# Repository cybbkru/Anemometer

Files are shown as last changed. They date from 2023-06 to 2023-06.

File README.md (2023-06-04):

# Anemometer 
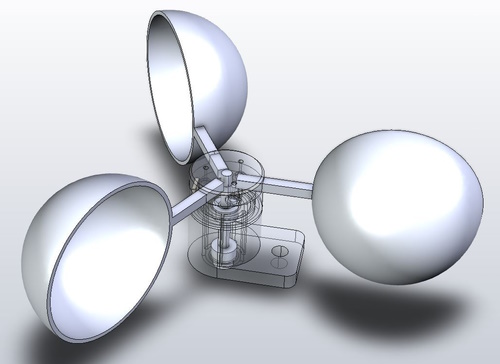
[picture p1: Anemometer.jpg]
"Main picture"


In my home ventilation unit this Anemometer helps to clear filters in time ( before air flow becomes too low). 

Hall-sensor and magnet are used to generate impulses according to rotation rate of Anemometer.

The "Sonoff basic" esp8266 wifi-relay flashed with Tasmota firmware used to count sesnsor impulses. (In my vent. unit it also enables/disables fan.)
You can use ANY ESP8266 based device (cheapest ESP-01 for example) having 1 free pin.

To count impulses attach Counter1 to RX pin of module (GPIO2 and GPIO14 are also available in some untits, you can try another available pin):
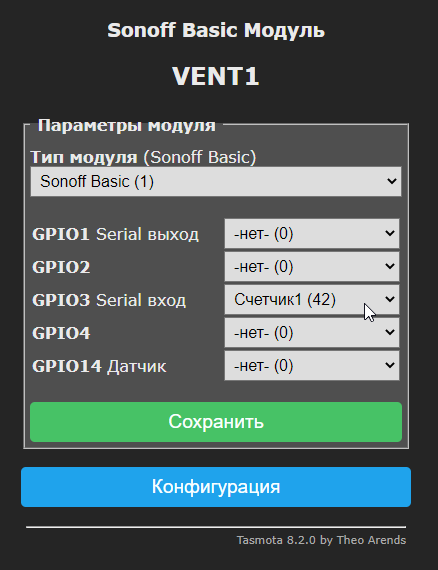
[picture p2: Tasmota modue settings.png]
"Settings"


Example for RX pin:
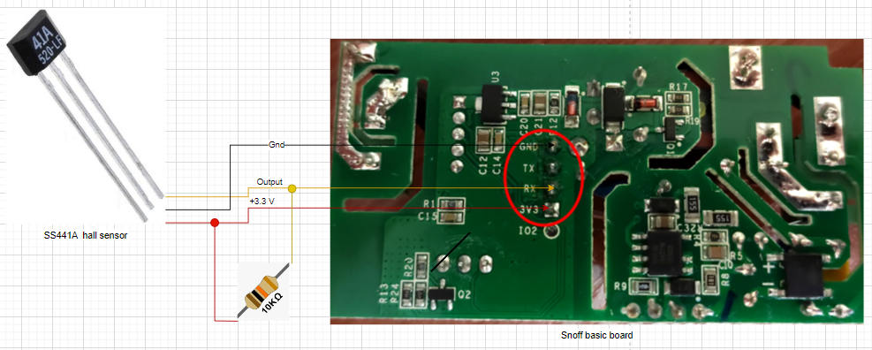
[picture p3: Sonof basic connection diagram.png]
"Wiring"


To publish counted impulses every 10 seconds to  MQTT topic "wind/vent1" use commands in Tasmota console:
```
Teleperiod 10
rule1 on tele-counter#c1>-1 do publish wind/vent1 %value% endon on tele-counter#c1>0 do counter1 0 endon
rule1 1
```

# Restrictions
Indoor use only.

# TODO
1. Draw printable bottom cover with cable gland.
2. Redraw design for outdoor use (enlarge clearances and parts overlays to prevent raindrops infiltration).

# TIPS
* Using eDrawings free STEP viewer to explore 3D model of assembled device (anemometer assembly.STEP) is more convenient than embedded STL-viewer of GitHUB.
* Test the magnet and SS441A BEFORE gluing magnet to printed part - this sensor is magnet direction sensitive! 
* SS441A is documented to work 3.8v and higher, using at 3.3 v is not good, but in my case 2 sensors work fine.
* STL files are ready to print.
* SolidWorks 2021 required to edit models.

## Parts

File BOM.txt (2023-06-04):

# BOM
Bearing D1=2mm D2=5mm h=2.5mm;        2 pcs;  to buy;
Steel pin D=2mm L=23mm (drill d=2mm); 1 pcs;  to buy;	
Hall sensor SS441A;                   1 pcs;  to buy;
Screw M1.2 L=3.5mm;                   3 pcs;  to buy;
Resistor 10k;                         1 pcs;  to buy;
Magnet 3.5 x 3.5 x 0.7 mm;            1 pcs;  to buy or to magnetize iron piece;

Cup;                                  3 pcs;  to print;
Base;                                 1 pcs;  to print;
Rayholder;                            1 pcs;  to print;
Rotor;                                1 pcs;  to print;
Lock;                                 1 pcs;  to print;

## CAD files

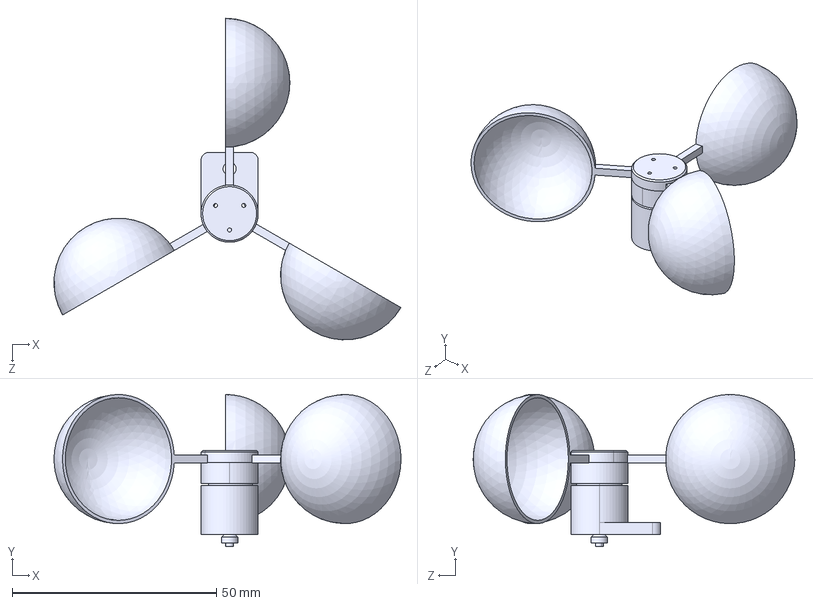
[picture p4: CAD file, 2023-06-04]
anemometer assembly.STEP
84.9 x 37.2 x 78.7 mm
cup x 3
rotor
axis
magnet
bearing x 2
rayholder
base
lock
ss441a

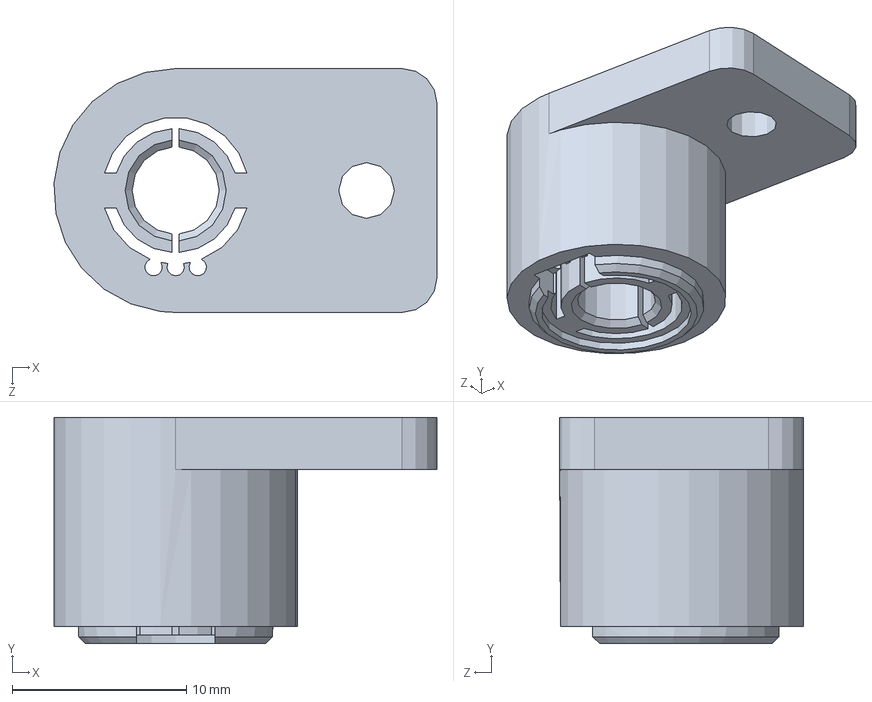
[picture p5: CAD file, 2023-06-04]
editable parts/base.SLDPRT
22.0 x 13.0 x 14.0 mm

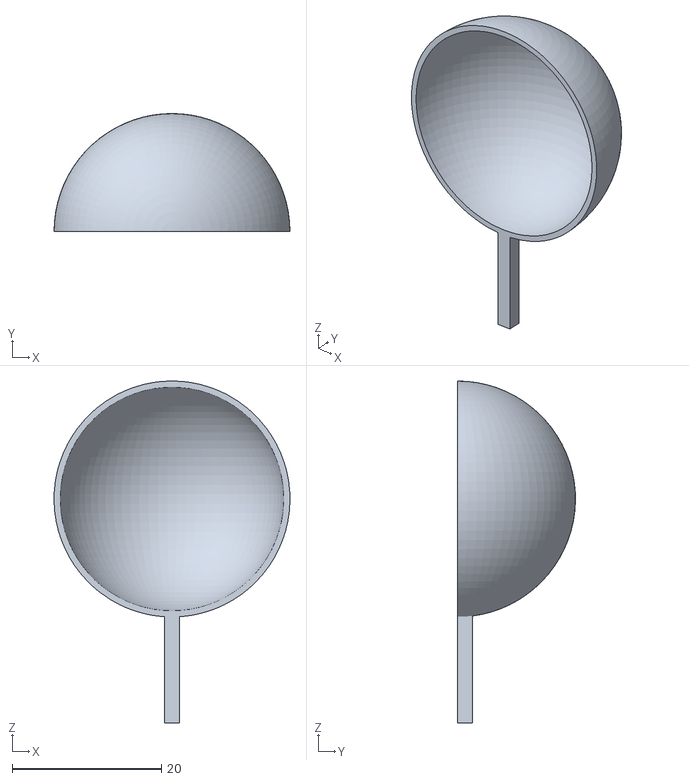
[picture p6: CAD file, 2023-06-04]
printable parts/cup.STL
31.6 x 15.8 x 45.8

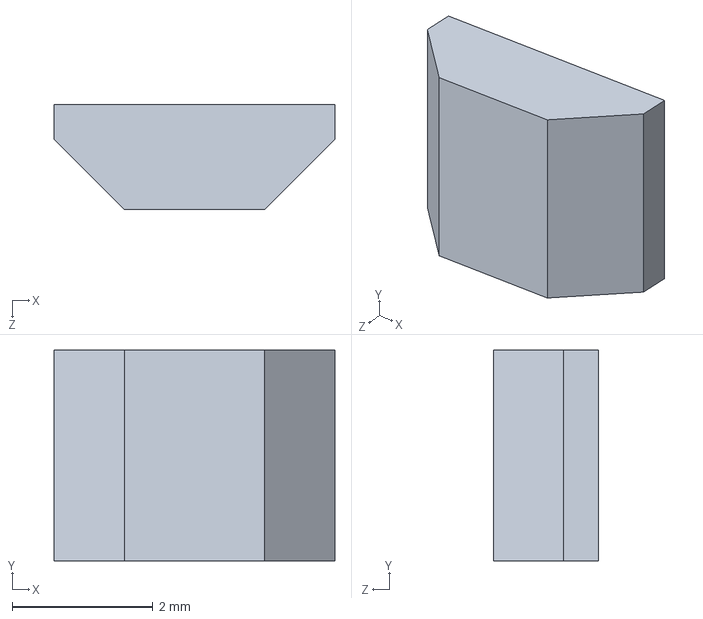
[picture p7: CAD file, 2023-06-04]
editable parts/ss441a.SLDPRT
4.00 x 3.00 x 1.50 mm

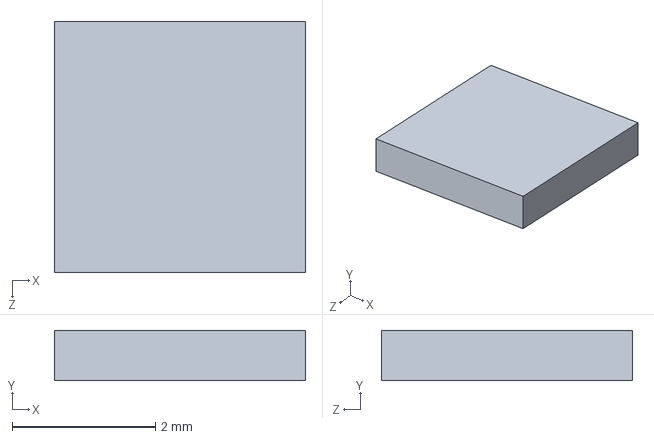
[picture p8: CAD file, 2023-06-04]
editable parts/magnet.SLDPRT
3.50 x 0.7 x 3.50 mm

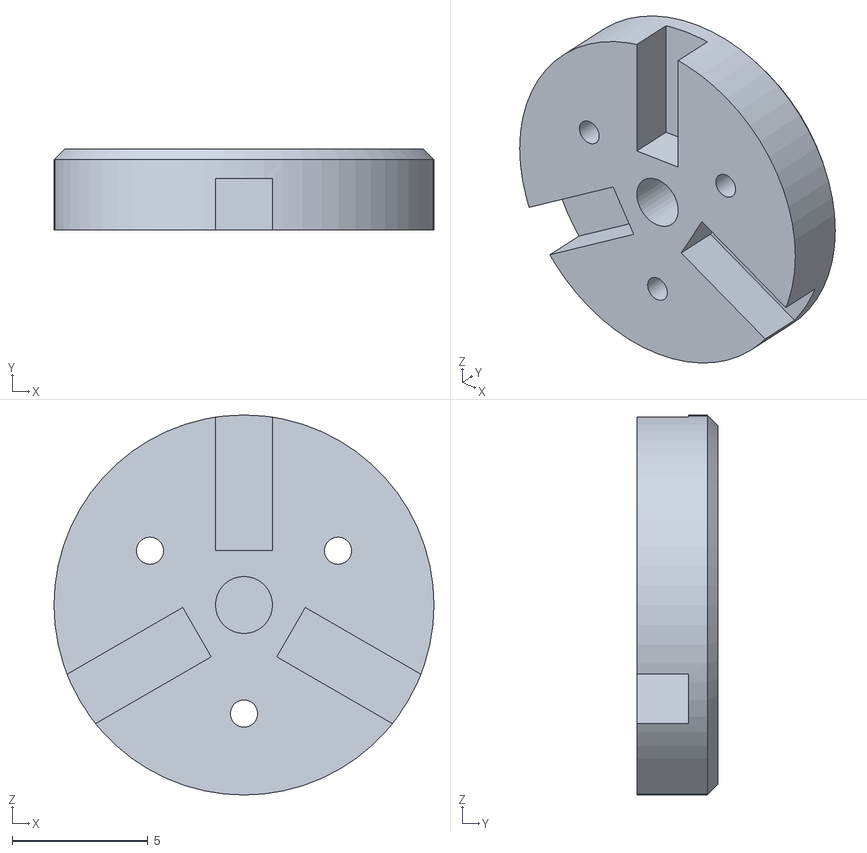
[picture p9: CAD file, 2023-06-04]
printable parts/rayholder.STL
14.0 x 3.00 x 14.0

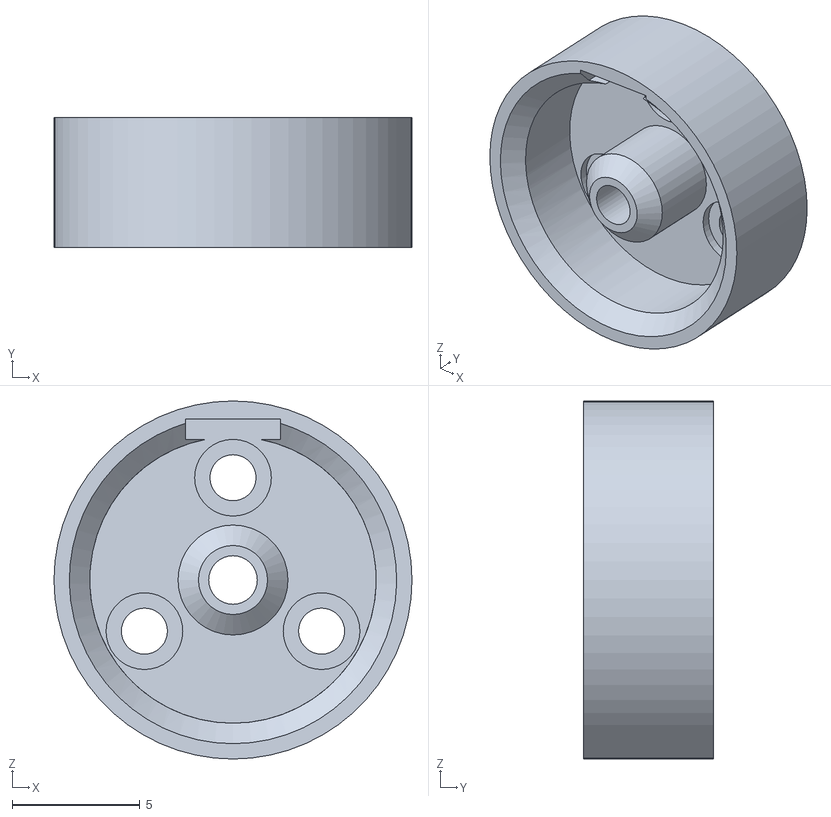
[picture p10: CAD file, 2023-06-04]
printable parts/rotor.STL
14.0 x 5.10 x 14.0

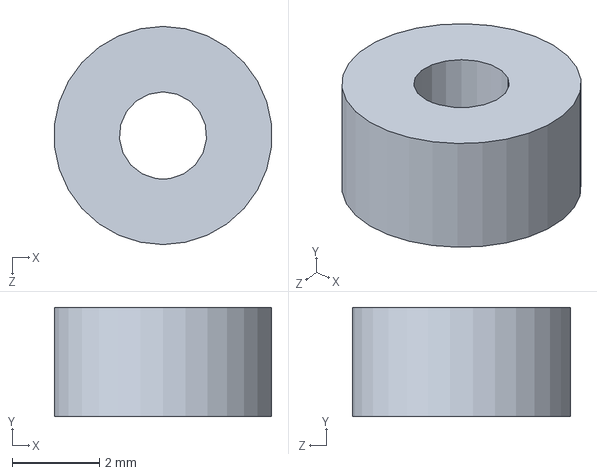
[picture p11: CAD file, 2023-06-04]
editable parts/bearing.SLDPRT
4.97 x 2.50 x 5.00 mm

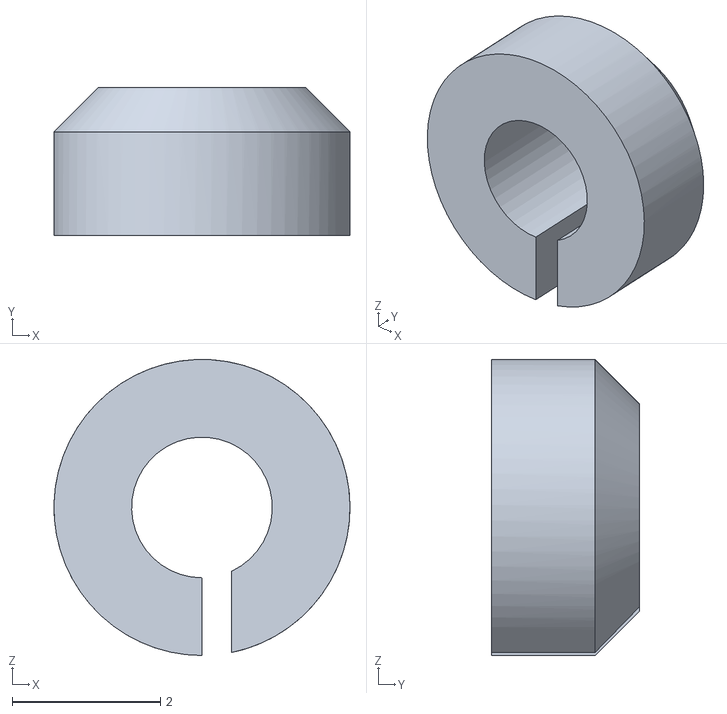
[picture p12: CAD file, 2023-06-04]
printable parts/lock.STL
4.00 x 2.00 x 4.00

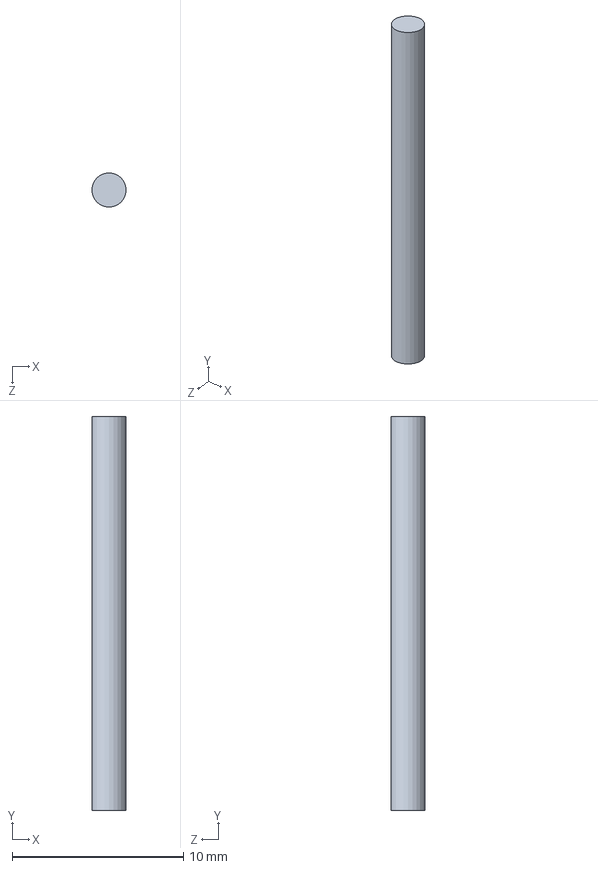
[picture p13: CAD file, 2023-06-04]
editable parts/axis.SLDPRT
2.00 x 23.0 x 2.00 mm

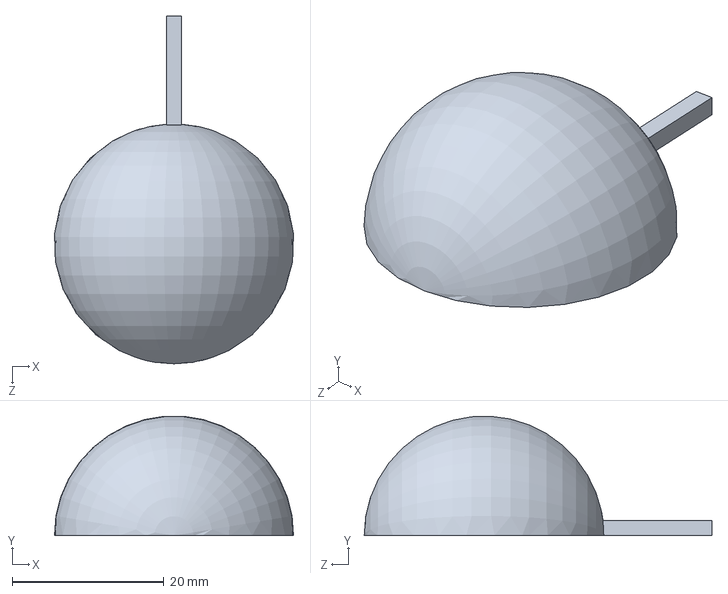
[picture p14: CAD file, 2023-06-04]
editable parts/cup.SLDPRT
31.5 x 15.7 x 45.8 mm

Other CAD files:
editable parts/anemometer assembly.SLDASM
printable parts/base.STL
editable parts/lock.SLDPRT
editable parts/rayholder.SLDPRT
editable parts/rotor.SLDPRT
anemometer assembly.STL

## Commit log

2023-06-04 Обновление Диаграмма без названия.drawio
2023-06-04 Initial upload
    Initial upload
    [anemometer assembly.SLDASM, anemometer assembly.STEP, axis.SLDPRT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]
2023-06-04 Добавлено anemometer.drawio
2023-06-04 Обновление anemometer.drawio
